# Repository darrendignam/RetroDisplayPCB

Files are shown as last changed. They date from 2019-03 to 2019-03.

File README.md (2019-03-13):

# RetroDisplayPCB

This repo is part a wider Tickertape Retro Display project that you can use to create your own Internet of Things LED display with that retro feel.

Check out the website, and my other project for the code library for Arduino and ESP32 for the rest of the project.

* http://tickertape.cc/
* https://github.com/darrendignam/LED_Display_Wrapper

# How the project works

Eagle version 9.1.3 was used on a Windows PC to create these files.
Some of the parts used, were made specifically for this project, and can be found here too.

In addition to the standard libraries the following Eagle libraries were also used:

    holtek-led-controller-v1
    
    Holtek Semiconductor Inc. Devices
    RAM Mapping 16*8 LED Controller Driver with keyscan
    SOP28, SOP24, SOP20
    www.holtek.com
    Created by S.Hofmann mc_sho@gmx.de
    
* http://eagle.autodesk.com/eagle/download/444

Various SparkFun libraries:
    
    SparkFun-Aesthetics
    SparkFun-Capacitors
    SparkFun-Connectors
    SparkFun-LED
    
* https://github.com/sparkfun/SparkFun-Eagle-Libraries
    
All of these are easy to find either in the library manager, or from the github pages for these projects. The sparkfun link has further great information for using Eagle and custom libraries installing them, everything. So I won't try and replicate that here!

# License Information
This library is released under the [Creative Commons ShareAlike 4.0 International license](https://creativecommons.org/licenses/by-sa/4.0/). You are welcome to use this library for commercial purposes. For attribution, we ask that when you begin to sell your device, you email us with a link to the product being sold. It would be great to see where this project goes, and will perhaps feature it on the website.

Together we can help the open-source hardware community continue to thrive and grow!

This project uses the 1206 LED footprint and some other helpful parts from the SparkFun projects listed above to help with the project. None of them were modified, they were used as-is.

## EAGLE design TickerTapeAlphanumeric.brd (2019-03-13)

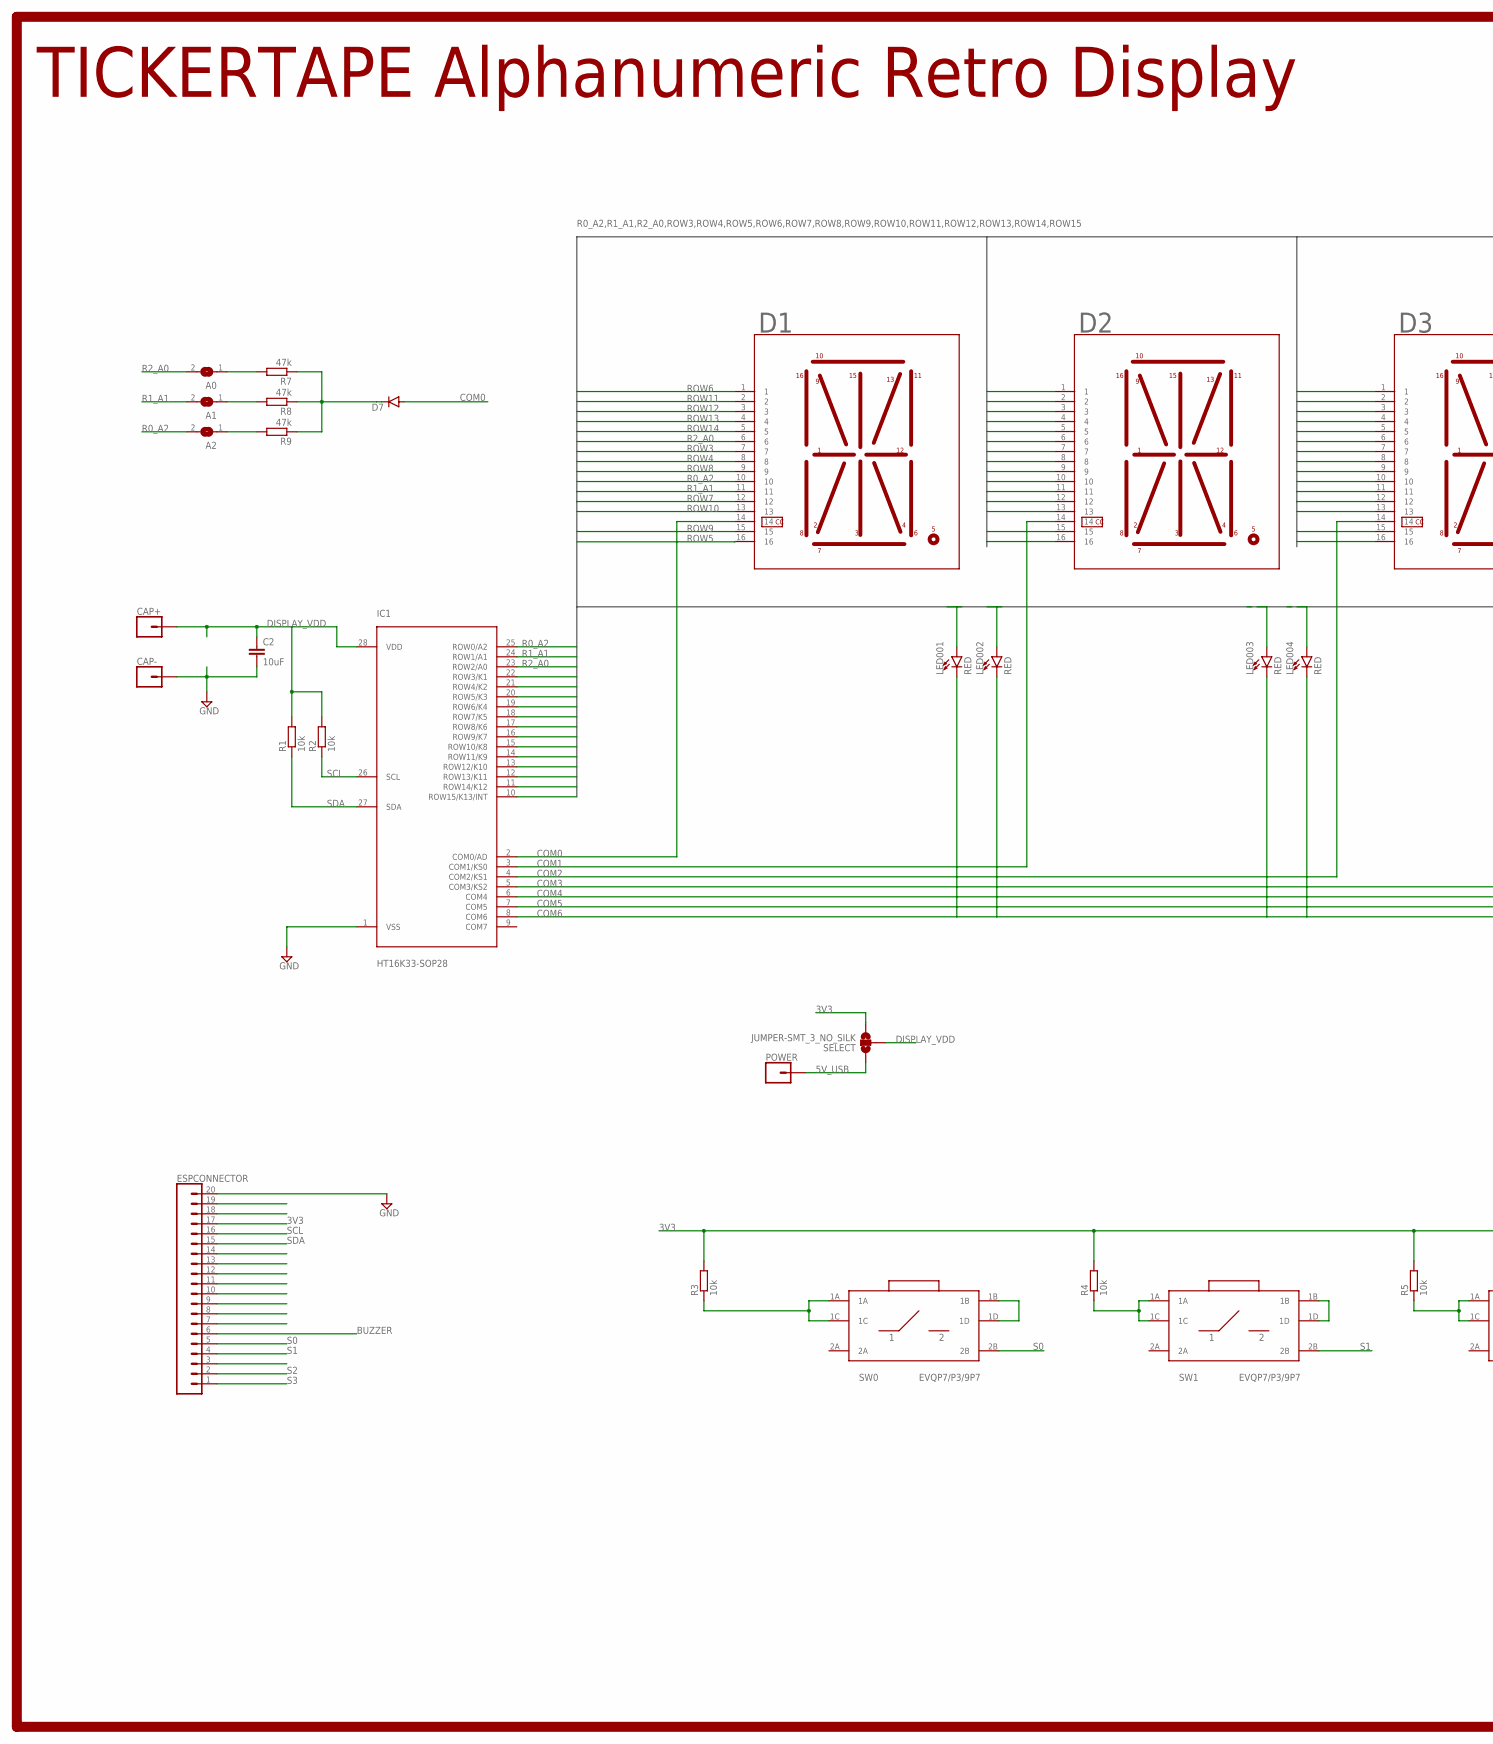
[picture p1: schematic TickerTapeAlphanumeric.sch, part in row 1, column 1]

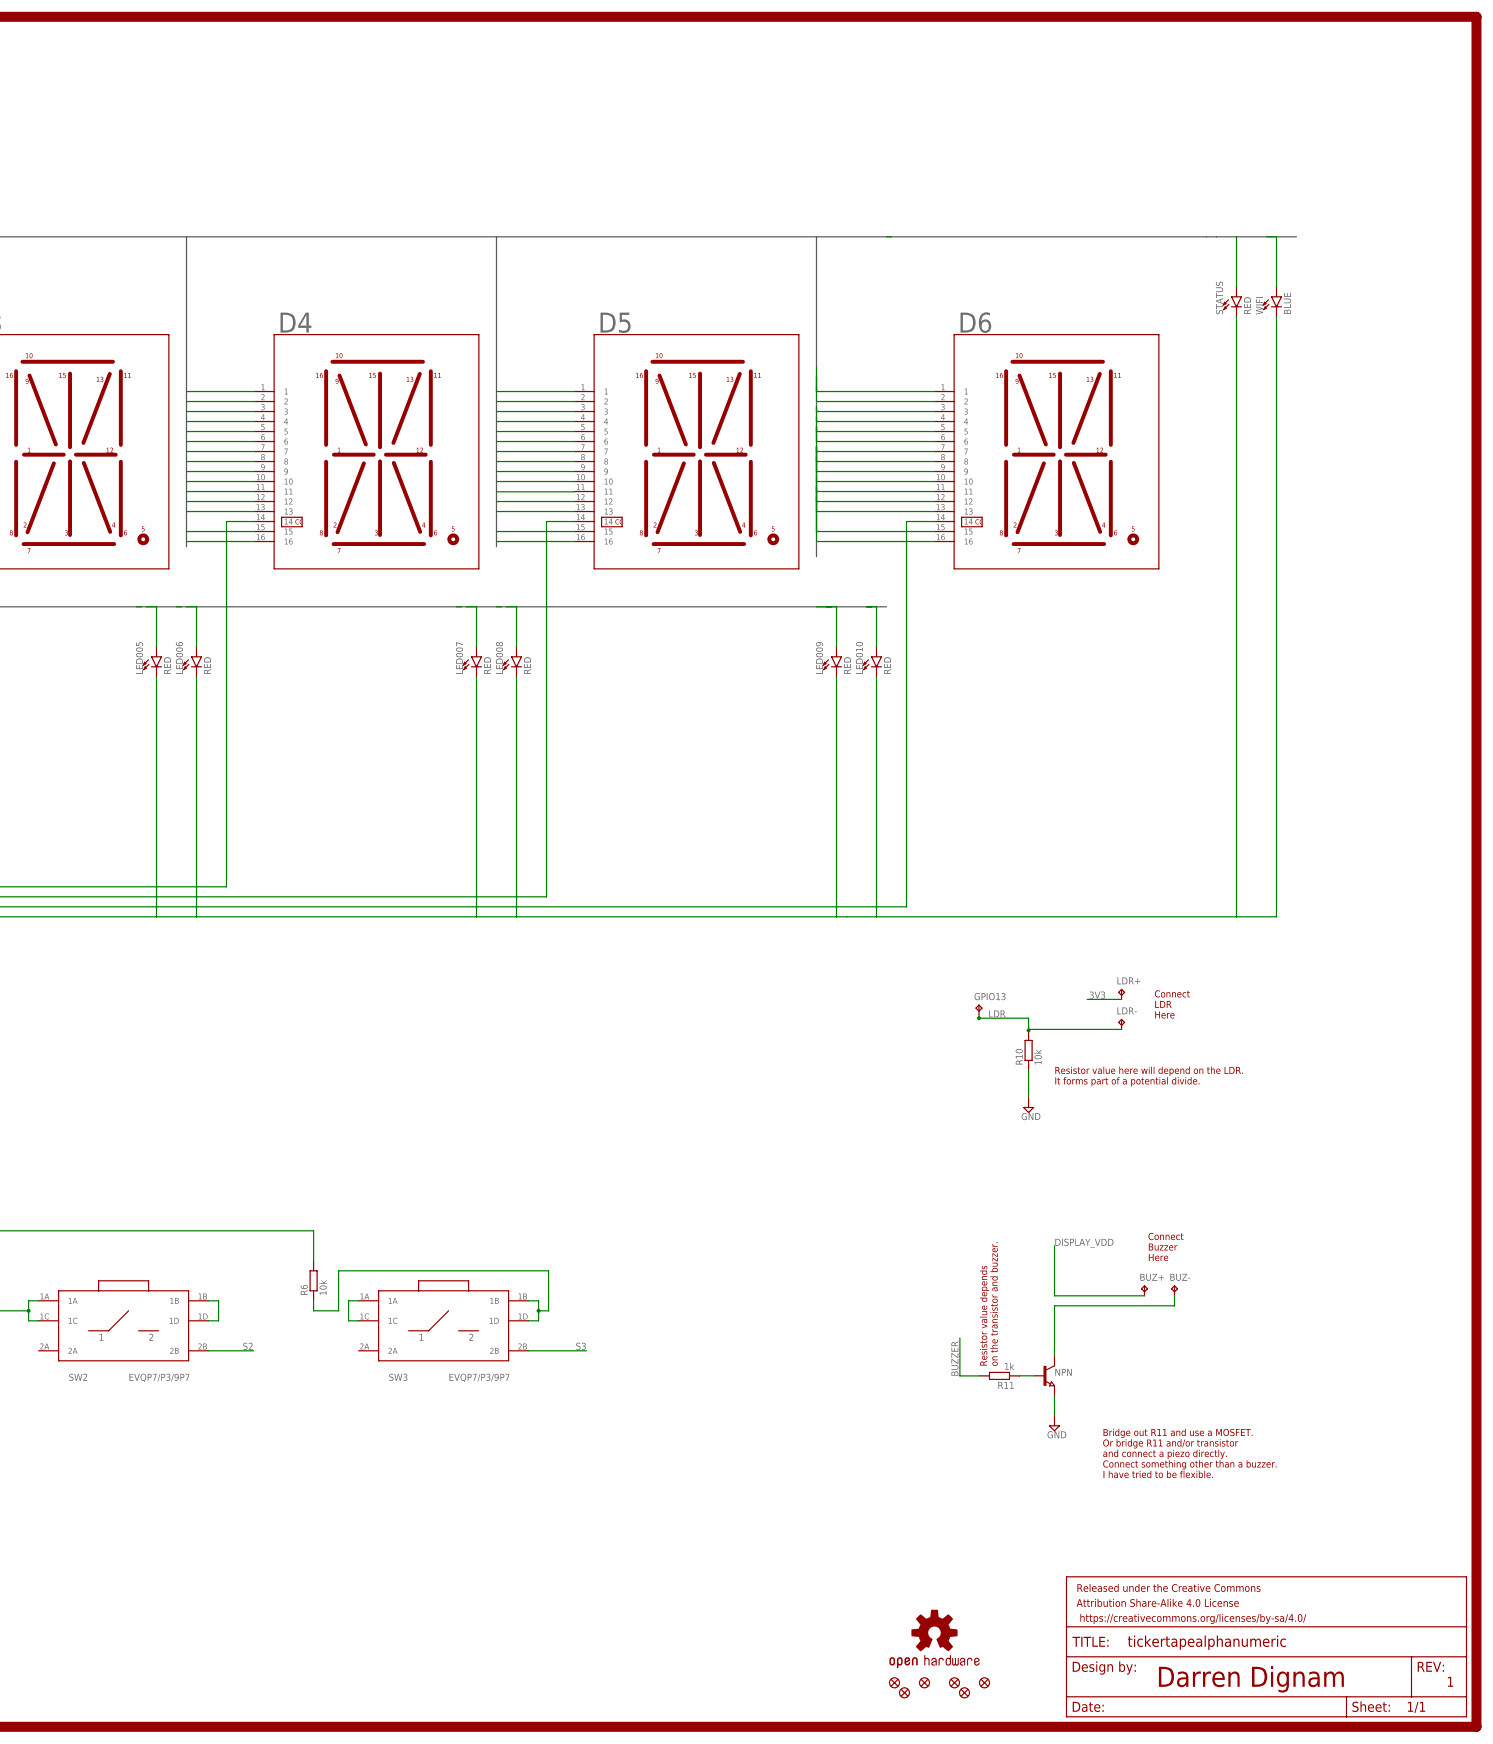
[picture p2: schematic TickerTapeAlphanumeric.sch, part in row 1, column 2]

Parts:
A0, A1, A2: SOLDERJUMPERREFLOW_NOPASTE; SOLDERJUMPER_REFLOW_NOPASTE
BUZ+: TPB1,27; B1,27
BUZ-: TPB1,27; B1,27
C2: 10uF; 1206
CAP+: CONN_01; 1X01
CAP-: CONN_01; 1X01
D1, D2, D3, D4, D5, D6: KCPSC04-105; 14-SEGMENT-LED
D7: DIODE-SOD323-W; SOD323-W
ESPCONNECTOR: CONN_20; 1X20
FD1, FD2, FD3, FD4, FD5, FD6: FIDUCIALUFIDUCIAL; FIDUCIAL-MICRO
FRAME1: FRAME-LEDGER; CREATIVE_COMMONS
GPIO13: TPB1,27; B1,27
IC1: HT16K33-SOP28; SOIC127P1031X264-28N
LDR+: TPB1,27; B1,27
LDR-: TPB1,27; B1,27
LED001, LED002, LED003, LED004, LED005, LED006, LED007, LED008, LED009, LED010: RED; LED-1206
LOGO1: OSHW-LOGOM-COPPER; OSHW-LOGO-M_COPPER
NPN: NPN-TRANSISTOR_SOT23; SOT23
POWER: CONN_01; 1X01
R1, R2, R10: 10k; R1206
R3, R4, R5, R6: 10k; R0603
R7, R8, R9: 47k; R1206
R11: 1k; R1206
SELECT: JUMPER-SMT_3_NO_SILK; SMT-JUMPER_3_NO_SILK
STATUS: RED; LED-1206
SW0, SW1, SW2, SW3: EVQP7/P3/9P7; SMT5.5MMX2.5MM
WIFI: BLUE; LED-1206

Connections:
3V3: ESPCONNECTOR.17, LDR+.TP, R3.2, R4.2, R5.2, R6.2, SELECT.3
5V_USB: POWER.1, SELECT.1
BUZZER: ESPCONNECTOR.6, R11.2
COM0: D1.14, D7.A, IC1.2 (COM0/AD)
COM1: D2.14, IC1.3 (COM1/KS0)
COM2: D3.14, IC1.4 (COM2/KS1)
COM3: D4.14, IC1.5 (COM3/KS2)
COM4: D5.14, IC1.6 (COM4)
COM5: D6.14, IC1.7 (COM5)
COM6: IC1.8 (COM6), LED001.C, LED002.C, LED003.C, LED004.C, LED005.C, LED006.C, LED007.C, LED008.C, LED009.C, LED010.C, STATUS.C, WIFI.C
DISPLAY_VDD: BUZ+.TP, C2.1, CAP+.1, IC1.28 (VDD), R1.2, R2.2, SELECT.2
GND: C2.2, CAP-.1, ESPCONNECTOR.20, IC1.1 (VSS), NPN.2 (E), R10.1
LDR: GPIO13.TP, LDR-.TP, R10.2
unnamed: R3.1, SW0.1A, SW0.1C
unnamed: SW0.1B, SW0.1D
unnamed: R4.1, SW1.1A, SW1.1C
unnamed: SW1.1B, SW1.1D
unnamed: BUZ-.TP, NPN.3 (C)
unnamed: R6.1, SW3.1B, SW3.1D
unnamed: D7.C, R7.1, R8.1, R9.1
unnamed: A0.1, R7.2
unnamed: A1.1, R8.2
unnamed: R5.1, SW2.1A, SW2.1C
unnamed: SW2.1B, SW2.1D
unnamed: SW3.1A, SW3.1C
unnamed: A2.1, R9.2
unnamed: NPN.1 (B), R11.1
R0_A2: A2.2, D1.10, D2.10, D3.10, D4.10, D5.10, D6.10, IC1.25 (ROW0/A2), LED001.A
R1_A1: A1.2, D1.11, D2.11, D3.11, D4.11, D5.11, D6.11, IC1.24 (ROW1/A1), LED002.A
R2_A0: A0.2, D1.6, D2.6, D3.6, D4.6, D5.6, D6.6, IC1.23 (ROW2/A0), LED003.A
ROW3: D1.7, D2.7, D3.7, D4.7, D5.7, D6.7, IC1.22 (ROW3/K1), LED004.A
ROW4: D1.8, D2.8, D3.8, D4.8, D5.8, D6.8, IC1.21 (ROW4/K2), LED005.A
ROW5: D1.16, D2.16, D3.16, D4.16, D5.16, D6.16, IC1.20 (ROW5/K3), LED006.A
ROW6: D1.1, D2.1, D3.1, D4.1, D5.1, D6.1, IC1.19 (ROW6/K4), LED007.A
ROW7: D1.12, D2.12, D3.12, D4.12, D5.12, D6.12, IC1.18 (ROW7/K5), LED008.A
ROW8: D1.9, D2.9, D3.9, D4.9, D5.9, D6.9, IC1.17 (ROW8/K6), LED009.A
ROW9: D1.15, D2.15, D3.15, D4.15, D5.15, D6.15, IC1.16 (ROW9/K7), LED010.A
ROW10: D1.13, D2.13, D3.13, D4.13, D5.13, D6.13, IC1.15 (ROW10/K8), STATUS.A
ROW11: D1.2, D2.2, D3.2, D4.2, D5.2, D6.2, IC1.14 (ROW11/K9), WIFI.A
ROW12: D1.3, D2.3, D3.3, D4.3, D5.3, D6.3, IC1.13 (ROW12/K10)
ROW13: D1.4, D2.4, D3.4, D4.4, D5.4, D6.4, IC1.12 (ROW13/K11)
ROW14: D1.5, D2.5, D3.5, D4.5, D5.5, D6.5, IC1.11 (ROW14/K12)
ROW15: IC1.10 (ROW15/K13/INT)
S0: ESPCONNECTOR.5, SW0.2B
S1: ESPCONNECTOR.4, SW1.2B
S2: ESPCONNECTOR.2, SW2.2B
S3: ESPCONNECTOR.1, SW3.2B
SCL: ESPCONNECTOR.16, IC1.26 (SCL), R2.1
SDA: ESPCONNECTOR.15, IC1.27 (SDA), R1.1

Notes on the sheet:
TICKERTAPE Alphanumeric Retro Display
Darren Dignam
Connect LDR Here
Connect Buzzer Here
Resistor value here will depend on the LDR. It forms part of a potential divide.
Resistor value depends on the transistor and buzzer.
Bridge out R11 and use a MOSFET. Or bridge R11 and/or transistor and connect a piezo directly. Connect something other than a buzzer. I have tried to be flexible.

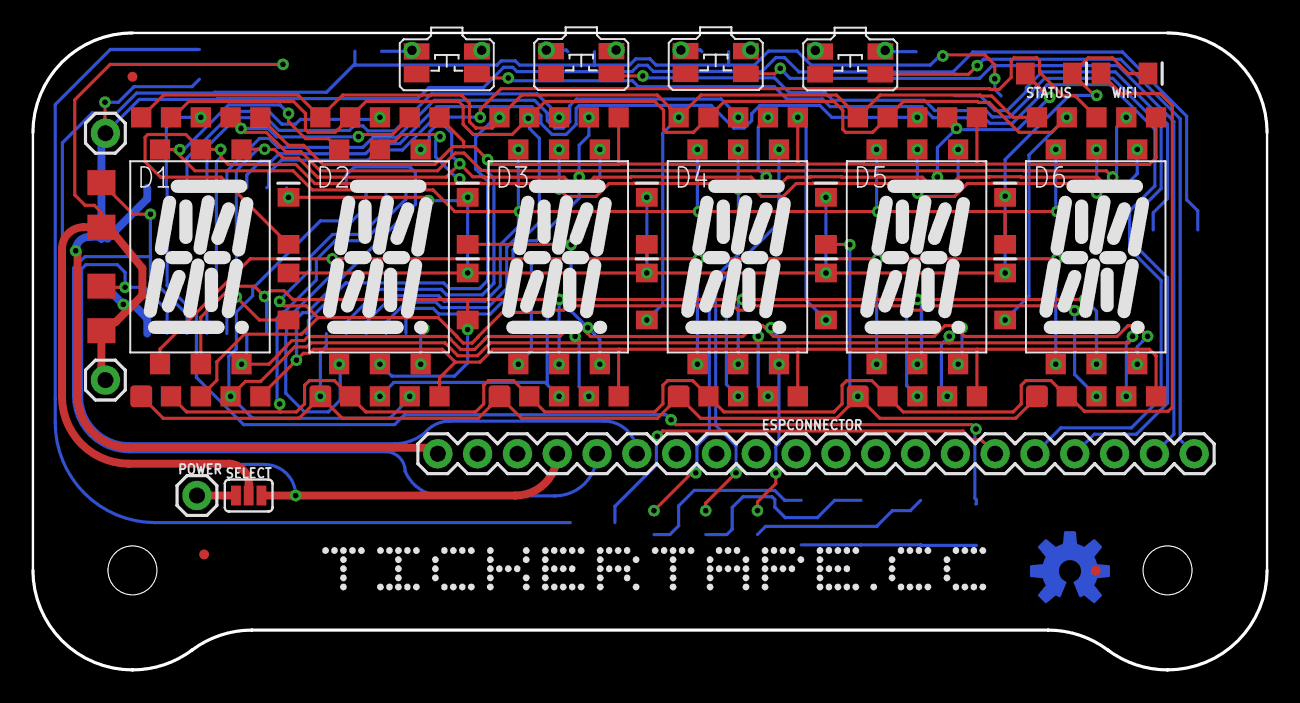
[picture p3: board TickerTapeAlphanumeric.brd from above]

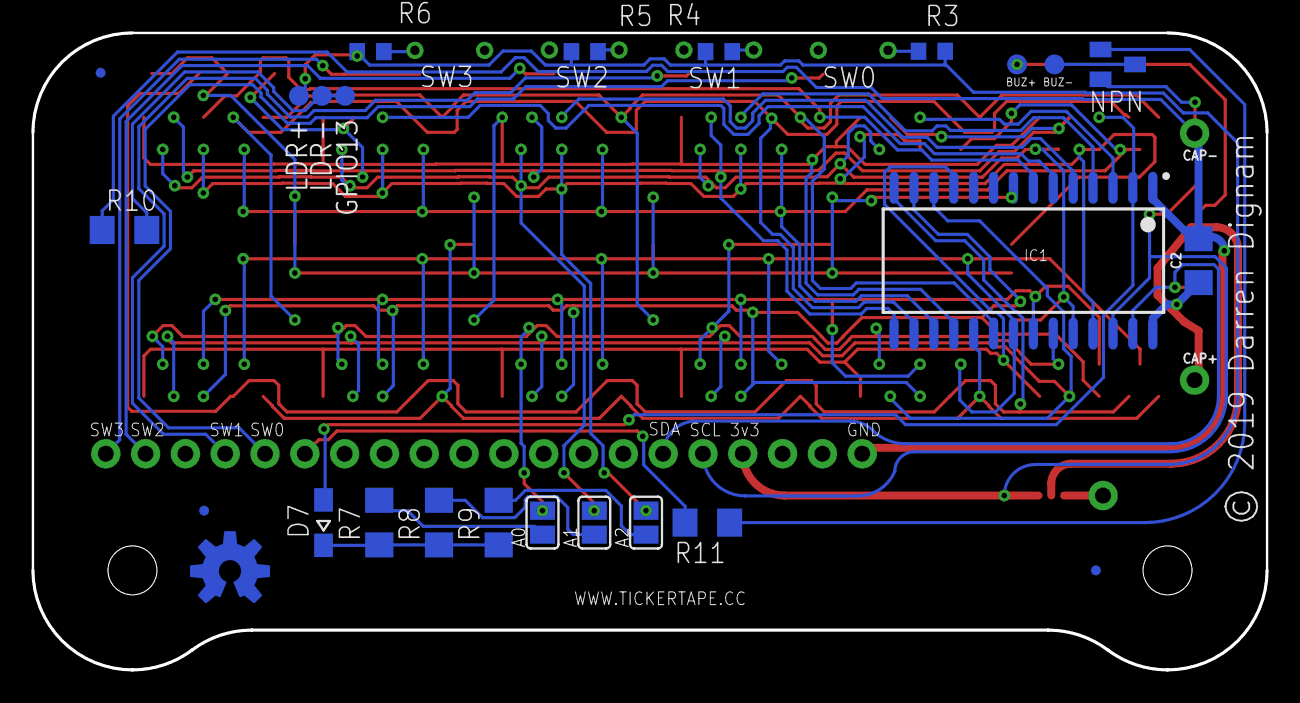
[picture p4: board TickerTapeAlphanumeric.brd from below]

Board: 2 copper layers, 78.7 x 40.6 mm, 58 parts (25 on the bottom side), 48 nets.

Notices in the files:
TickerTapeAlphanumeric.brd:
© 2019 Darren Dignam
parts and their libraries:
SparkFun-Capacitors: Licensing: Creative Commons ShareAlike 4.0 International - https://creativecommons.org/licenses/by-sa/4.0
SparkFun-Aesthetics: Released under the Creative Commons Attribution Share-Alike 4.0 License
